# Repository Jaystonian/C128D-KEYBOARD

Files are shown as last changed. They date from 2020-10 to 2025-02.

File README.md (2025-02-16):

# C128D-KEYBOARD

Mechanical C128D Keyboard replacement using CherryMX keys

2020-10-08:
 * Gerber files of keyboard PCB uploaded 
  (control board gerbers and all KIKAD files will follow shortly)
 
 * STL 3D printables uploaded

2025-02-16:
 * Updated all gerber files.
 * Fixed the capslock problem
 * All keys function correctly to date

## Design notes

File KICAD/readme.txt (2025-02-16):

V1.04:
 * Sorry if I've left things a bit messy, as I had used one 
schematic file to support two pcb files.
 * LEDs were quite dim, 220R resistors are better suited.

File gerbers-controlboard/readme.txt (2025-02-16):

V1.04: Fixed the behaviour of locking keys during power-up and use.
To use this version of control board with the original keyboard which
I designed 2020, you need to remove D103, C7, R93 and R95 from under the
CapsLock key, then connect the button switch directly to the control line
(pin 2 on the SIP-40).  You may also omit all signal diodes from the
keyboard PCB, replacing them with 0-ohm resistors or jumpers. The new
keyboard revision has all of these fixes in place.

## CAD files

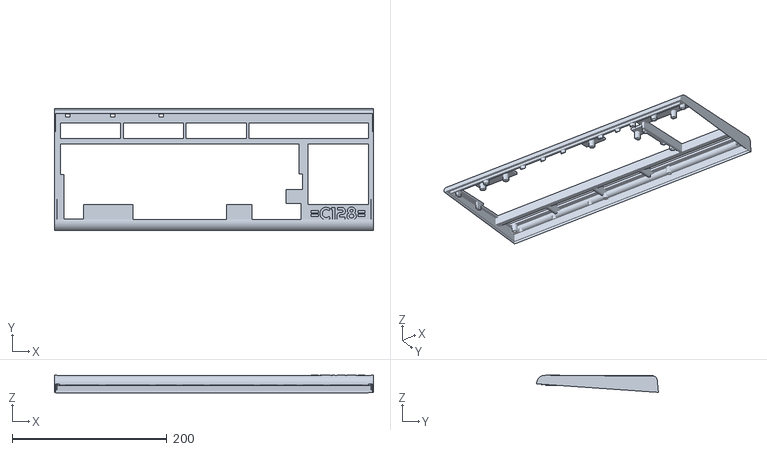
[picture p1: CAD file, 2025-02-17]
3D-PRINT-STL/C128-TOP-V3.stl
412.0 x 157.3 x 23.0

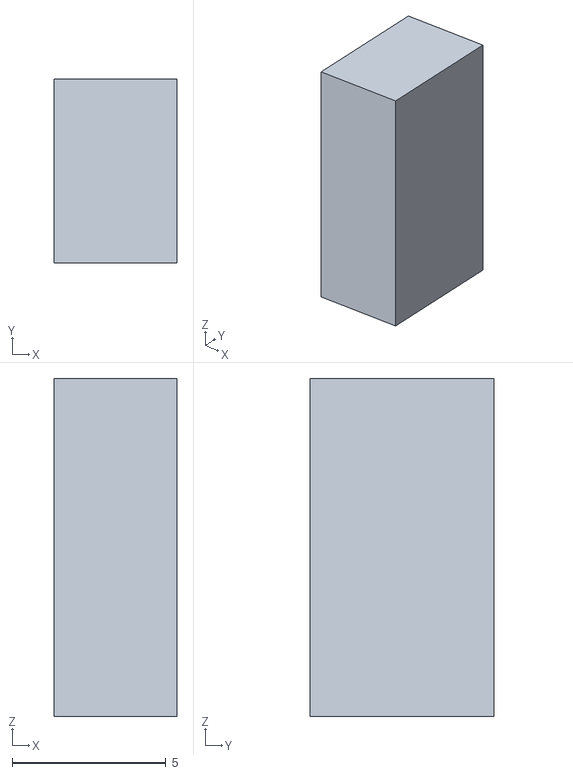
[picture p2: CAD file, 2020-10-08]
3D-PRINT-STL/C128-LED-4x6x11-clear-PETG.stl
4.00 x 6.00 x 11.0

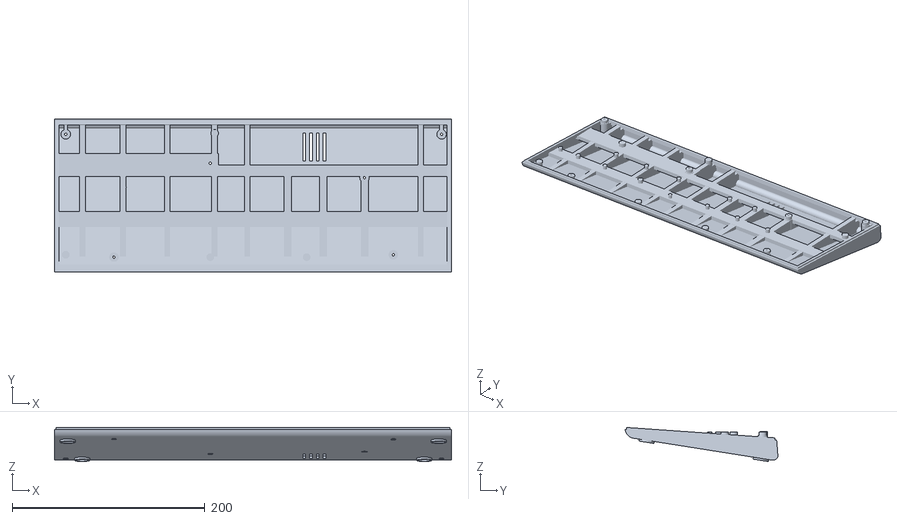
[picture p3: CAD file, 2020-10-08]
3D-PRINT-STL/C128-BOTTOM-V1.stl
412.0 x 158.7 x 35.4

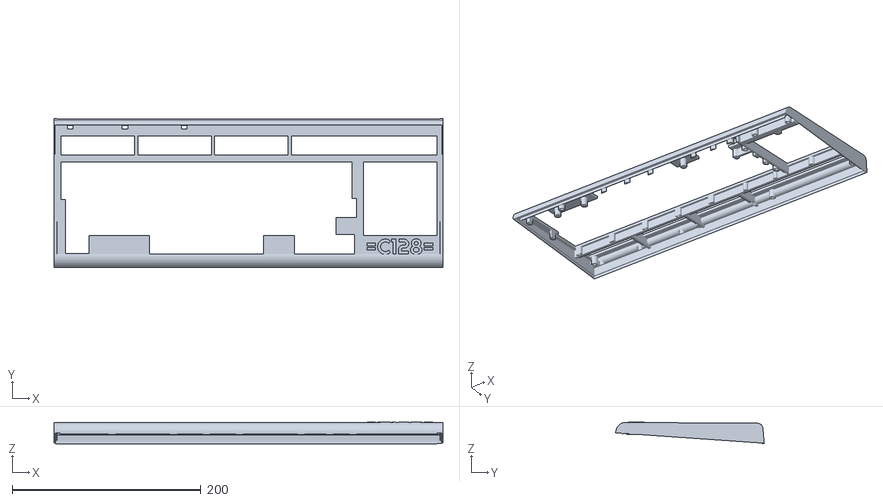
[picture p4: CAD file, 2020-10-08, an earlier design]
3D-PRINT-STL/C128-TOP-V1.stl
412.0 x 157.3 x 23.0

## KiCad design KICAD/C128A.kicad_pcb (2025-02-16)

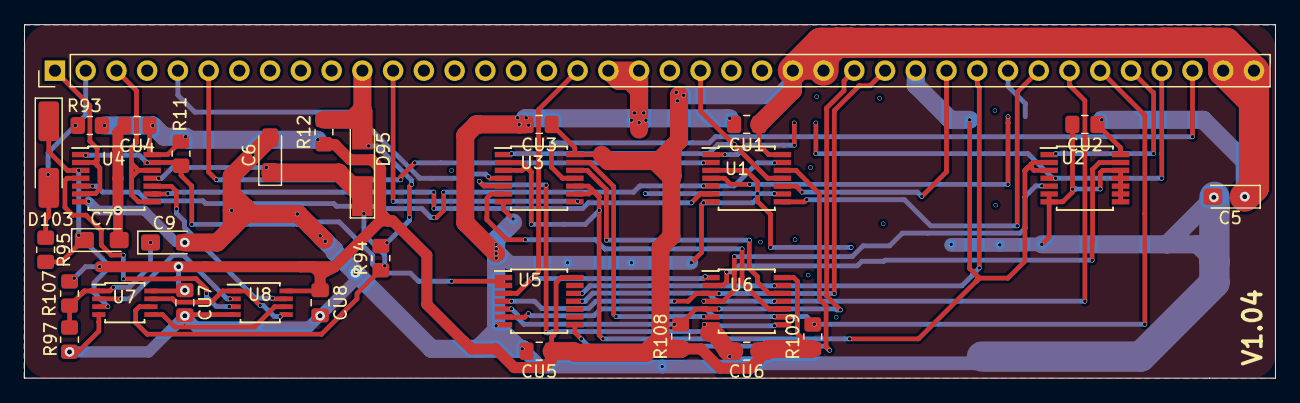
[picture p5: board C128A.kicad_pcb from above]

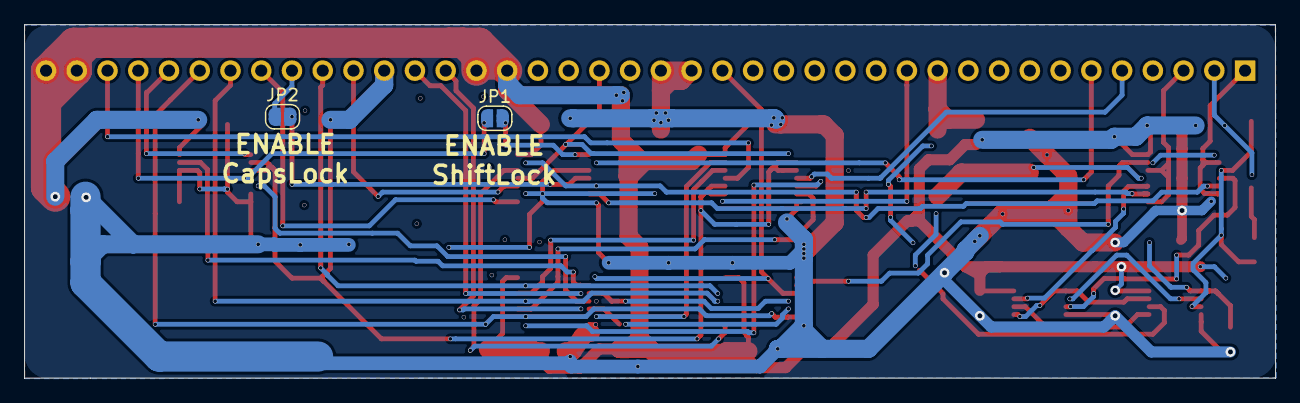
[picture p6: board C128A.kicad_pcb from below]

Board: 2 copper layers, 103.4 x 29.2 mm, 34 parts (2 on the bottom side), 43 nets.

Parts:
C5: 10uF; CP_EIA-3216-10_Kemet-I_Pad1.58x1.35mm_HandSolder
C6, C7, C9: 10u; CP_EIA-3216-10_Kemet-I_Pad1.58x1.35mm_HandSolder
CU1, CU2, CU3, CU4, CU5, CU6, CU7, CU8: 100nF; C_0805_2012Metric_Pad1.18x1.45mm_HandSolder
D95, D103: D_MiniMELF_Handsoldering
J2: Conn_01x40; PinHeader_1x40_P2.54mm_Vertical
JP1, JP2: SolderJumper_2_Open; SolderJumper-2_P1.3mm_Open_RoundedPad1.0x1.5mm
R11: 22K; R_0805_2012Metric_Pad1.20x1.40mm_HandSolder
R12, R93: 10K; R_0805_2012Metric_Pad1.20x1.40mm_HandSolder
R94, R95, R107: 2K7; R_0805_2012Metric_Pad1.20x1.40mm_HandSolder
R97: 5K6; R_0805_2012Metric_Pad1.20x1.40mm_HandSolder
R108, R109: 47K; R_0805_2012Metric_Pad1.20x1.40mm_HandSolder
U1, U2, U3: 74HCT4066PW,118; TSSOP-14_4.4x5mm_P0.65mm
U4: 74HCT74PW,118; TSSOP-14_4.4x5mm_P0.65mm
U5: 74HCT30PW,118; TSSOP-14_4.4x5mm_P0.65mm
U6: 74HCT04PW,118; TSSOP-14_4.4x5mm_P0.65mm
U7: 74HCT3G04DP,125; TSSOP-8_3x3mm_P0.65mm
U8: 74HCT2G00DP,125; TSSOP-8_3x3mm_P0.65mm

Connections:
+5V: C5.1, CU1.1, CU2.1, CU3.1, CU4.1, CU5.1, CU6.1, CU7.1, CU8.1, J2.25, J2.26, J2.39, J2.40, R11.1, R12.1, R93.1, R107.1, R108.1, R109.1, U1.14 (VDD), U2.14 (VDD), U3.14 (VDD), U4.14 (VCC), U5.14 (VCC), U6.14 (VCC), U7.8 (VCC), U8.8 (VCC)
/DCL: D103.2 (A), J2.2, R93.2, R95.2
/P05: J2.38, U3.11
/P06: J2.12, U3.8
/P07: J2.5, U3.4
/P08: J2.22, U1.11, U3.1
/P09: J2.37, JP1.1 (A), U2.4
/P10: J2.36, U2.1
/P13: J2.29, U2.2, U2.3, U3.2, U3.3, U3.9, U3.10
/P14: J2.30, U1.10
/P19: J2.6, U1.2
/P24: J2.33, U1.8
/P25: J2.32, JP2.1 (A)
/P4080: D95.2 (A), J2.11, R12.2, R94.2
/PULLUP: R11.2, U4.1 (~R), U4.13 (~R), U5.1, U5.2
/~PushCL: J2.18, U5.3, U6.1
/~PushCU: J2.28, U5.4, U6.3
/~PushF2: J2.27, R108.2, U5.5, U6.5
/~PushF4: J2.35, R109.2, U5.6, U6.9
/~PushF6: J2.34, U5.11, U6.11
/~PushF8: J2.31, U5.12, U6.13
/~Q4080: J2.3, U4.8 (~Q), U4.12 (D)
/~QCL: J2.1, U4.2 (D), U4.6 (~Q)
/~SRS: U7.7, U8.1, U8.5
GND: C5.2, C6.2, C7.2, C9.2, CU1.2, CU2.2, CU3.2, CU4.2, CU5.2, CU6.2, CU7.2, CU8.2, J2.19, J2.20, R97.2, U1.3, U1.7 (VSS), U1.9, U2.6, U2.7 (VSS), U2.8, U2.9, U2.10, U2.11, U2.12, U3.7 (VSS), U4.7 (GND), U5.7 (GND), U6.7 (GND), U7.4 (GND), U8.4 (GND)
unnamed: C9.1, R97.1, R107.2, U7.1
unnamed: C6.1, D95.1 (K), R94.1, U4.11 (C), U7.6
unnamed: C7.1, D103.1 (K), R95.1, U4.3 (C), U7.3
unnamed: JP1.2 (B), U1.1
unnamed: JP2.2 (B), U1.4
unnamed: U1.12, U5.8
unnamed: U2.5, U6.4
unnamed: U2.13, U6.2
unnamed: U3.5, U6.8
unnamed: U3.6, U6.10
unnamed: U3.12, U6.12
unnamed: U3.13, U6.6
unnamed: U1.5, U1.13, U4.5 (Q)
unnamed: U4.4 (~S), U8.3
unnamed: U1.6, U4.9 (Q)
unnamed: U4.10 (~S), U8.7
unnamed: U7.2, U8.2
unnamed: U7.5, U8.6

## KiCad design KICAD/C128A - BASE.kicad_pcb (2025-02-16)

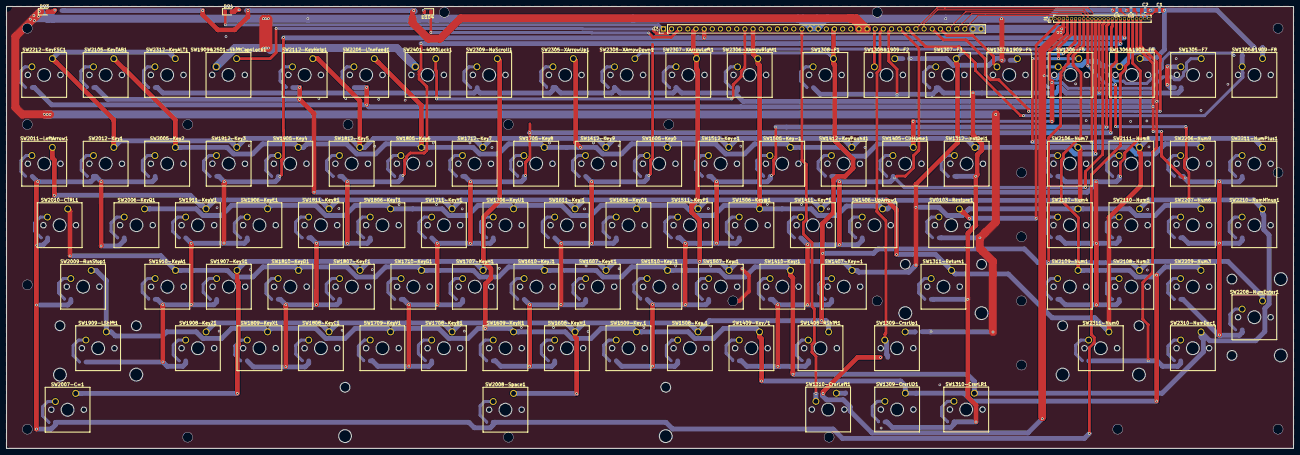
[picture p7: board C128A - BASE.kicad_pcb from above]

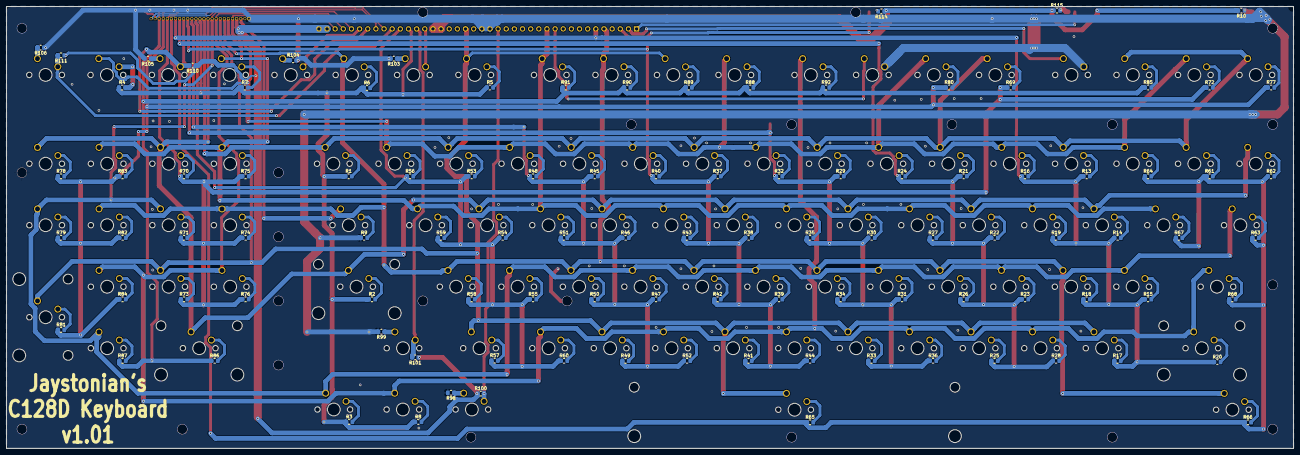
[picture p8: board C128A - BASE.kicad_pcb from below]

Board: 2 copper layers, 401.3 x 137.8 mm, 208 parts (102 on the bottom side), 132 nets.

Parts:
C1, C2, C3, C4: 220pF; C_0805_2012Metric_Pad1.18x1.45mm_HandSolder
D93: LED_POWER; LED_0805_2012Metric_Pad1.15x1.40mm_HandSolder
D94: LED_Caps; LED_0805_2012Metric_Pad1.15x1.40mm_HandSolder
D104: LED_4080; LED_0805_2012Metric_Pad1.15x1.40mm_HandSolder
J1: Conn_01x25; PinHeader_1x25_P1.27mm_Vertical
J2: Conn_01x40; PinHeader_1x40_P2.54mm_Vertical
R1, R2, R3, R4, R5, R6, R7, R8, R9, R13, R14, R15, R16, R17, R18, R19, R20, R21, R22, R23, R24, R25, R26, R27, R28, R29, R30, R31, R32, R33, R34, R35, R36, R37, R38, R39, R40, R41, R42, R43, R44, R45, R46, R47, R48, R49, R50, R51, R52, R53, R54, R55, R56, R57, R58, R59, R60, R61, R62, R63, R64, R65, R66, R67, R68, R69, R70, R71, R72, R73, R74, R75, R76, R77, R78, R79, R80, R81, R82, R83, R84, R85, R86, R87, R88, R89, R90, R91, R92: 120R; R_0805_2012Metric_Pad1.20x1.40mm_HandSolder
R10, R114, R115: 1k5; R_0805_2012Metric_Pad1.20x1.40mm_HandSolder
R98, R99, R103, R105, R106: 10K; R_0805_2012Metric_Pad1.20x1.40mm_HandSolder
R100, R101, R110, R111: 47K; R_0805_2012Metric_Pad1.20x1.40mm_HandSolder
R104: 10k; R_0805_2012Metric_Pad1.20x1.40mm_HandSolder
SW0103-Restore1, SW2010-CTRL1: SW_Push; SW_Cherry_MX_1.50u_PCB
SW1305&1909-F8, SW1305-F7, SW1306&1909-F6, SW1306-F5, SW1307&1909-F4, SW1307-F3, SW1308&1909-F2, SW1308-F1, SW1310-CrsrLR1, SW1310-CrsrLeft1, SW1312-InstDel1, SW1405-ClrHome1, SW1406-UpArrow1, SW1407-Key=1, SW1409-Key/1, SW1410-Key;1, SW1411-Key*1, SW1412-KeyPound1, SW1505-Key-1, SW1506-Key@1, SW1507-Key:1, SW1508-Key.1, SW1509-Key,1, SW1510-KeyL1, SW1511-KeyP1, SW1512-Key+1, SW1605-Key0, SW1606-KeyO1, SW1607-KeyK1, SW1608-KeyM1, SW1609-KeyN1, SW1610-KeyJ1, SW1611-KeyI1, SW1612-Key9, SW1705-Key8, SW1706-KeyU1, SW1707-KeyH1, SW1708-KeyB1, SW1709-KeyV1, SW1710-KeyG1, SW1711-KeyY1, SW1712-Key7, SW1805-Key6, SW1806-KeyT1, SW1807-KeyF1, SW1808-KeyC1, SW1809-KeyX1, SW1810-KeyD1, SW1811-KeyR1, SW1812-Key5, SW1905-Key4, SW1906-KeyE1, SW1907-KeyS1, SW1908-KeyZ1, SW1909&2501-ShiftCapsLock1, SW1910-KeyA1, SW1911-KeyW1, SW1912-Key3, SW2005-Key2, SW2006-KeyQ1, SW2011-LeftArrow1, SW2012-Key1, SW2105-KeyTAB1, SW2106-Num7, SW2107-Num4, SW2108-Num2, SW2109-Num1, SW2110-Num5, SW2111-Num8, SW2112-KeyHelp1, SW2205-LineFeed1, SW2206-Num9, SW2207-Num6, SW2209-Num3, SW2210-NumMinus1, SW2211-NumPlus1, SW2212-KeyESC1, SW2305-XArrowUp1, SW2306-XArrowRight1, SW2307-XArrowLeft1, SW2308-XArrowDown1, SW2309-NoScroll1, SW2310-NumDec1, SW2312-KeyALT1, SW2401-4080Lock1: SW_Push; SW_Cherry_MX_1.00u_PCB
SW1309-CrsrUD1, SW1309-CrsrUp1, SW1408-RShift1, SW2007-C=1: SW_Push; SW_Cherry_MX_1.25u_PCB
SW1311-Return1, SW1909-LShift1: SW_Push; SW_Cherry_MX_2.25u_PCB
SW2008-Space1: SW_Push; SW_Cherry_MX_6.25u_PCB
SW2009-RunStop1: SW_Push; SW_Cherry_MX_1.75u_PCB
SW2208-NumEnter1: SW_Push; SW_Cherry_MX_2.00u_Vertical_PCB
SW2311-Num0: SW_Push; SW_Cherry_MX_2.00u_PCB

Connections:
+5V: J1.4, J2.25, J2.26, J2.39, J2.40, R10.2, R100.1, R101.1, R110.1, R111.1, R114.1, R115.1
/DCL: J2.2, SW1909&2501-ShiftCapsLock1.1
/P03: J1.3, SW0103-Restore1.1
/P05: J1.5, J2.38, SW1305-F7.1, SW1405-ClrHome1.1, SW1505-Key-1.1, SW1605-Key0.1, SW1705-Key8.1, SW1805-Key6.1, SW1905-Key4.1, SW2005-Key2.1, SW2105-KeyTAB1.1, SW2205-LineFeed1.1, SW2305-XArrowUp1.1
/P06: J1.6, J2.12, SW1306-F5.1, SW1406-UpArrow1.1, SW1506-Key@1.1, SW1606-KeyO1.1, SW1706-KeyU1.1, SW1806-KeyT1.1, SW1906-KeyE1.1, SW2006-KeyQ1.1, SW2106-Num7.1, SW2206-Num9.1, SW2306-XArrowRight1.1
/P07: J1.7, J2.5, SW1307-F3.1, SW1407-Key=1.1, SW1507-Key:1.1, SW1607-KeyK1.1, SW1707-KeyH1.1, SW1807-KeyF1.1, SW1907-KeyS1.1, SW2007-C=1.1, SW2107-Num4.1, SW2207-Num6.1, SW2307-XArrowLeft1.1
/P08: J1.8, J2.22, SW1308-F1.1, SW1408-RShift1.1, SW1508-Key.1.1, SW1608-KeyM1.1, SW1708-KeyB1.1, SW1808-KeyC1.1, SW1908-KeyZ1.1, SW2008-Space1.1, SW2108-Num2.1, SW2208-NumEnter1.1, SW2308-XArrowDown1.1
/P09: J1.9, J2.37, SW1309-CrsrUD1.1, SW1409-Key/1.1, SW1509-Key,1.1, SW1609-KeyN1.1, SW1709-KeyV1.1, SW1809-KeyX1.1, SW1909-LShift1.1, SW2009-RunStop1.1, SW2109-Num1.1, SW2209-Num3.1, SW2309-NoScroll1.1
/P10: J1.10, J2.36, SW1310-CrsrLR1.1, SW1410-Key;1.1, SW1510-KeyL1.1, SW1610-KeyJ1.1, SW1710-KeyG1.1, SW1810-KeyD1.1, SW1910-KeyA1.1, SW2010-CTRL1.1, SW2110-Num5.1, SW2210-NumMinus1.1, SW2310-NumDec1.1
/P11: J1.11, SW1311-Return1.1, SW1411-Key*1.1, SW1511-KeyP1.1, SW1611-KeyI1.1, SW1711-KeyY1.1, SW1811-KeyR1.1, SW1911-KeyW1.1, SW2011-LeftArrow1.1, SW2111-Num8.1, SW2211-NumPlus1.1, SW2311-Num0.1
/P12: J1.12, SW1312-InstDel1.1, SW1412-KeyPound1.1, SW1512-Key+1.1, SW1612-Key9.1, SW1712-Key7.1, SW1812-Key5.1, SW1912-Key3.1, SW2012-Key1.1, SW2112-KeyHelp1.1, SW2212-KeyESC1.1, SW2312-KeyALT1.1
/P13: J1.13, J2.29, R1.1, R2.1, R3.1, R4.1, R5.1, R6.1, R7.1, R8.1
/P14: J1.14, J2.30, R53.1, R54.1, R55.1, R56.1, R57.1, R58.1, R59.1, R60.1
/P15: J1.15, R45.1, R46.1, R47.1, R48.1, R49.1, R50.1, R51.1, R52.1
/P16: J1.16, R37.1, R38.1, R39.1, R40.1, R41.1, R42.1, R43.1, R44.1
/P17: J1.17, R29.1, R30.1, R31.1, R32.1, R33.1, R34.1, R35.1, R36.1
/P18: J1.18, R21.1, R22.1, R23.1, R24.1, R25.1, R26.1, R27.1, R28.1
/P19: J1.19, J2.6, R13.1, R14.1, R15.1, R16.1, R17.1, R18.1, R19.1, R20.1
/P20: J1.20, R61.1, R62.1, R63.1, R64.1, R65.1, R66.1, R67.1, R68.1
/P21: C4.1, J1.21, R69.1, R70.1, R71.1, R72.1, R73.1, R74.1, R75.1, R76.1
/P22: C3.1, J1.22, R77.1, R78.1, R79.1, R80.1, R81.1, R82.1, R83.1, R84.1
/P23: C2.1, J1.23, R85.1, R86.1, R87.1, R88.1, R89.1, R90.1, R91.1, R92.1
/P24: C1.1, J1.24, J2.33
/P25: J1.25, J2.32
/P4080: J2.11, SW2401-4080Lock1.1
/~PushCL: J2.18, R100.2, SW1310-CrsrLeft1.2
/~PushCU: J2.28, R101.2, SW1309-CrsrUp1.2
/~PushF2: J2.27, SW1308&1909-F2.2
/~PushF4: J2.35, SW1307&1909-F4.2
/~PushF6: J2.34, R110.2, SW1306&1909-F6.2
/~PushF8: J2.31, R111.2, SW1305&1909-F8.2
/~Q4080: D104.1 (K), J2.3
/~QCL: D94.1 (K), J2.1
GND: C1.2, C2.2, C3.2, C4.2, D93.1 (K), J1.1, J2.19, J2.20, R9.1, R98.2, R99.2, R103.2, R104.2, R105.2, R106.1, SW1909&2501-ShiftCapsLock1.2, SW2401-4080Lock1.2
unnamed: D93.2 (A), R10.1
unnamed: D94.2 (A), R115.2
unnamed: D104.2 (A), R114.2
unnamed: R1.2, SW1312-InstDel1.2
unnamed: R2.2, SW1311-Return1.2
unnamed: R3.2, SW1310-CrsrLR1.2
unnamed: R4.2, SW1305-F7.2
unnamed: R5.2, SW1308-F1.2
unnamed: R6.2, SW1307-F3.2
unnamed: R7.2, SW1306-F5.2
unnamed: R8.2, SW1309-CrsrUD1.2
unnamed: R9.2, SW0103-Restore1.2
unnamed: R13.2, SW1912-Key3.2
unnamed: R14.2, SW1911-KeyW1.2
unnamed: R15.2, SW1910-KeyA1.2
unnamed: R16.2, SW1905-Key4.2
unnamed: R17.2, SW1908-KeyZ1.2
unnamed: R18.2, SW1907-KeyS1.2
unnamed: R19.2, SW1906-KeyE1.2
unnamed: R20.2, SW1909-LShift1.2
unnamed: R21.2, SW1812-Key5.2
unnamed: R22.2, SW1811-KeyR1.2
unnamed: R23.2, SW1810-KeyD1.2
unnamed: R24.2, SW1805-Key6.2
unnamed: R25.2, SW1808-KeyC1.2
unnamed: R26.2, SW1807-KeyF1.2
unnamed: R27.2, SW1806-KeyT1.2
unnamed: R28.2, SW1809-KeyX1.2
unnamed: R29.2, SW1712-Key7.2
unnamed: R30.2, SW1711-KeyY1.2
unnamed: R31.2, SW1710-KeyG1.2
unnamed: R32.2, SW1705-Key8.2
unnamed: R33.2, SW1708-KeyB1.2
unnamed: R34.2, SW1707-KeyH1.2
unnamed: R35.2, SW1706-KeyU1.2
unnamed: R36.2, SW1709-KeyV1.2
unnamed: R37.2, SW1612-Key9.2
unnamed: R38.2, SW1611-KeyI1.2
unnamed: R39.2, SW1610-KeyJ1.2
unnamed: R40.2, SW1605-Key0.2
unnamed: R41.2, SW1608-KeyM1.2
unnamed: R42.2, SW1607-KeyK1.2
unnamed: R43.2, SW1606-KeyO1.2
unnamed: R44.2, SW1609-KeyN1.2
unnamed: R45.2, SW1512-Key+1.2
unnamed: R46.2, SW1511-KeyP1.2
unnamed: R47.2, SW1510-KeyL1.2
unnamed: R48.2, SW1505-Key-1.2
unnamed: R49.2, SW1508-Key.1.2
unnamed: R50.2, SW1507-Key:1.2
unnamed: R51.2, SW1506-Key@1.2
unnamed: R52.2, SW1509-Key,1.2
unnamed: R53.2, SW1412-KeyPound1.2
unnamed: R54.2, SW1411-Key*1.2
unnamed: R55.2, SW1410-Key;1.2
unnamed: R56.2, SW1405-ClrHome1.2
unnamed: R57.2, SW1408-RShift1.2
unnamed: R58.2, SW1407-Key=1.2
unnamed: R59.2, SW1406-UpArrow1.2
unnamed: R60.2, SW1409-Key/1.2
unnamed: R61.2, SW2012-Key1.2
unnamed: R62.2, SW2011-LeftArrow1.2
unnamed: R63.2, SW2010-CTRL1.2
unnamed: R64.2, SW2005-Key2.2
unnamed: R65.2, SW2008-Space1.2
unnamed: R66.2, SW2007-C=1.2
unnamed: R67.2, SW2006-KeyQ1.2
unnamed: R68.2, SW2009-RunStop1.2
unnamed: R69.2, SW2112-KeyHelp1.2
unnamed: R70.2, SW2111-Num8.2
unnamed: R71.2, SW2110-Num5.2
unnamed: R72.2, SW2105-KeyTAB1.2
unnamed: R73.2, SW2108-Num2.2
unnamed: R74.2, SW2107-Num4.2
unnamed: R75.2, SW2106-Num7.2
unnamed: R76.2, SW2109-Num1.2
unnamed: R77.2, SW2212-KeyESC1.2
unnamed: R78.2, SW2211-NumPlus1.2
unnamed: R79.2, SW2210-NumMinus1.2
unnamed: R80.2, SW2205-LineFeed1.2
unnamed: R81.2, SW2208-NumEnter1.2
unnamed: R82.2, SW2207-Num6.2
unnamed: R83.2, SW2206-Num9.2
unnamed: R84.2, SW2209-Num3.2
unnamed: R85.2, SW2312-KeyALT1.2
unnamed: R86.2, SW2311-Num0.2
unnamed: R87.2, SW2310-NumDec1.2
unnamed: R88.2, SW2305-XArrowUp1.2
unnamed: R89.2, SW2308-XArrowDown1.2
unnamed: R90.2, SW2307-XArrowLeft1.2
unnamed: R91.2, SW2306-XArrowRight1.2
unnamed: R92.2, SW2309-NoScroll1.2
unnamed: R98.1, SW1310-CrsrLeft1.1
unnamed: R99.1, SW1309-CrsrUp1.1
unnamed: R103.1, SW1308&1909-F2.1
unnamed: R104.1, SW1307&1909-F4.1
unnamed: R105.1, SW1306&1909-F6.1
unnamed: R106.2, SW1305&1909-F8.1

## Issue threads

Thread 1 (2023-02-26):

control board gerbers

au-chadl, 2023-02-26:
when are the control board gerbers going to be uploaded?

Jaystonian, 2023-04-24:
I've held back publishing the control board because it had a problem with the caps lock key. I redesigned it three times before realizing I need to move a couple components off the mainboard onto the control board.  I've been busy with more pressing matters and still intend to revisit this project for completion, including a jury-rig for existing keyboard PCBs to be able to use the new control board.  I can boost the priority for you and try to get this done in May 2023.  I would also like to have a fully functional keyboard!  Also the 3D Print needs some work, I was getting some terrible print quality being new to 3D printing at the time when I designed it and my prints have come a long way, the settings are dialed in quite nice today.  So I look forward to releasing a nice case as well.
